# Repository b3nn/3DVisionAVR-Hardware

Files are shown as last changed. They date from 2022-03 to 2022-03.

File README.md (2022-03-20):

# 3DVisionAVR-Hardware
Hardware design files and info for 3DVisionAVR, a clone for 3D Vision Emitter using IR. This is a hardware implementation to use with Lukis101's [3DVisionAVR](https://github.com/lukis101/3DVisionAVR) code

# Notice
This is at an early stage and may change significantly. It should not be considered a replacement for the official 3D Vision Emitter pyramid. You will likely notice limited range of the IR signal and sync issues. Consider this a work in progress which you can help test and improve

# Design Files
This was designed in Kicad v6 and uses [g200kg's kicad-lib-arduino](https://github.com/g200kg/kicad-lib-arduino) library for the Sparkfun Pro Micro

The main component is an Arduino Pro Micro. This should work fine with a clone version to save a few dollars. However, to make things easy, all items can be purchased via the [Sparkfun Wishlist 167547](https://www.sparkfun.com/wish_lists/167547) for around $50 USD. 

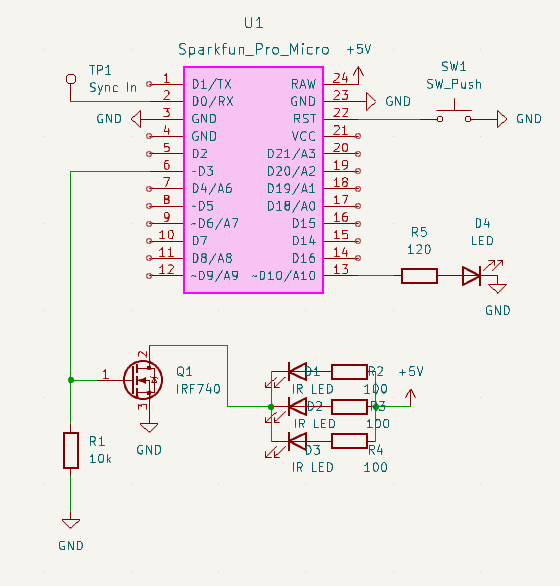
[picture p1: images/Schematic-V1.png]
schematic


# Breadboarding
The circuit is easy to create on a breadboard.

- Pro Micro PIN 3 is our IR Signal (goes to mosfet Gate)
- Pro Micro PIN 10 is USB Status light (goes to resistor to green led)
- Pro Micro RAW is IR LED Power (goes to positive rail)

Hook up GND on both sides of the Pro Micro to the negative rail. The mosfet source pin goes to GND and the middle drain pin goes to the cathode pin of the IR leds (short leg). Wire Pin 3 from the Pro Micro to the gate on the mosfet and then a pull down 10K resistor (connected to the negative rail). Each IR Led should have the anode (long leg) connected via a 100 ohm resistor to the RAW positive rail. Finally hook up the status LED to the signal on Pin 10 (it might be unlabeled but next to pin 16). 

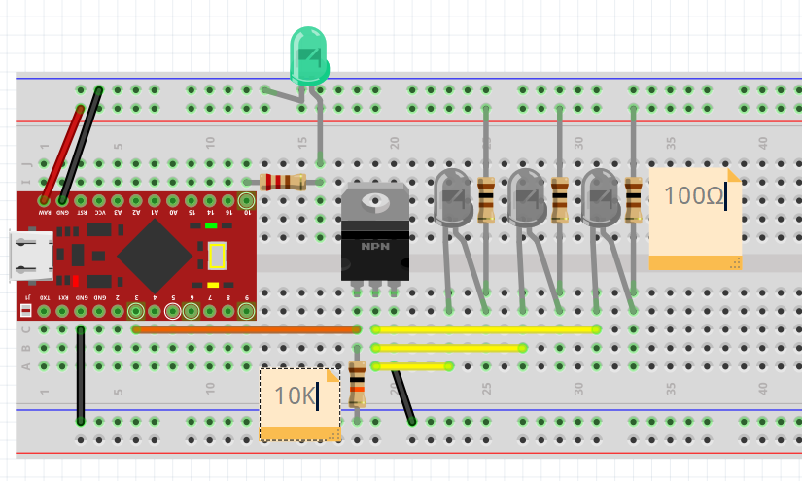
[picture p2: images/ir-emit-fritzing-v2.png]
Fritzing Breadboard


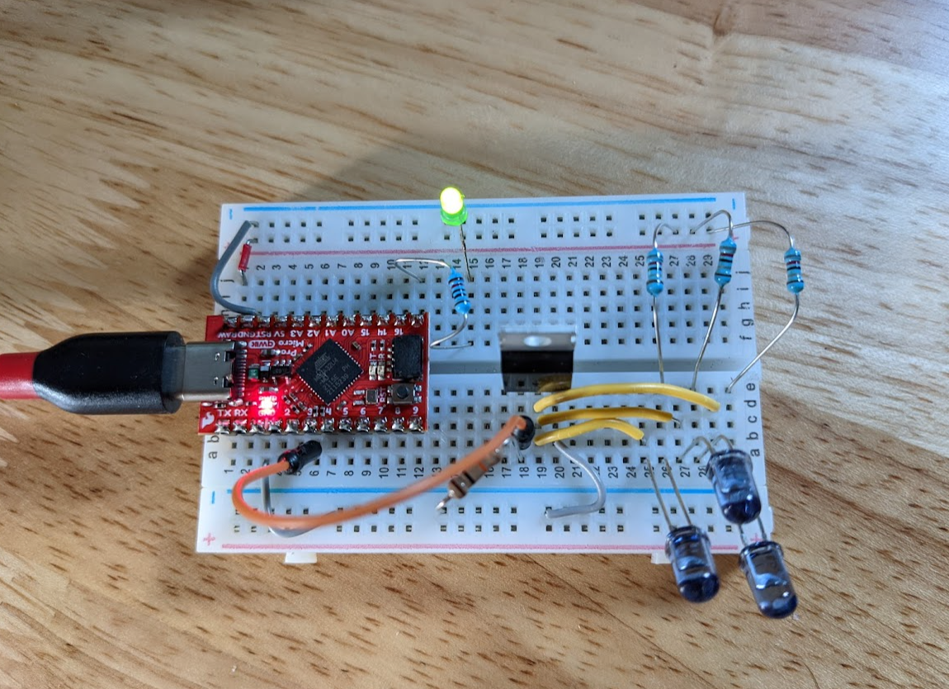
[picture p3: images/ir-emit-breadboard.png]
IRL Breadboard


Also if you are using the VESA sync, that goes into the Pro Micro PIN 2. Point the IR LEDs at your face for best results :-)

# PCB
I'm currently having this PCB fabricated, but all files are here if you would also like to fab your own. This is using common through-hole parts so it can be packaged into an easy to assemble kit.

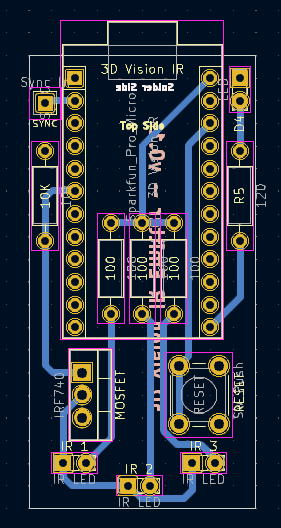
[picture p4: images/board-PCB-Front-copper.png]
PCB Front Copper


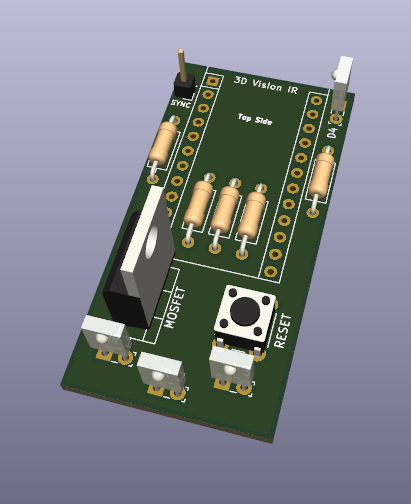
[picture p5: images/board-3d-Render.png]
board-3d-Render


# Flashing
For steps on compiling and flashing Lukis101's [3DVisionAVR](https://github.com/lukis101/3DVisionAVR) code for this project, view [README-FLASH-FIRMWARE.md](README-FLASH-FIRMWARE.md)

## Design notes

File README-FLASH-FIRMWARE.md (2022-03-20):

# 3DVisionAVR Firmware
Flashing the Arduino Pro Micro with the [3DVisionAVR](https://github.com/lukis101/3DVisionAVR) code does require a few tools and steps. In order to help others with that process, here is what worked for me on Windows 10.

Download and install [Arduino IDE](https://www.arduino.cc/en/software) and [Microchip Studio](https://www.microchip.com/en-us/tools-resources/develop/microchip-studio#Downloads) for AVR (at the time, my versions were Arduino 1.8.10 and Studio v7.0.2542). 

Download lukis101's code from Github and make sure to include the lufa submodule. I recommend using git command for this:

    git clone --recurse-submodules https://github.com/lukis101/3DVisionAVR.git

Next open the [3DvisionAVR.atsln](https://github.com/lukis101/3DVisionAVR/blob/master/3DVisionAVR.atsln) file in Microchip Studio. I made one change since I'm doing the software only driver. Open the [IREmitter.c](https://github.com/lukis101/3DVisionAVR/blob/master/3DVisionAVR/IREmitter.c#L40) file and change 

**IR_SetSyncMode(SYNCMODE_COMBINED);**

over to the software only driver mode

**IR_SetSyncMode(SYNCMODE_DRIVER);**

Save the file, then go under the BUILD menu to BUILD SOLUTION. Read the output window and make sure you got a "Build succeeded" message. At this point, you have the compiled code, but we need to flash that to the Pro Micro.

# Flashing

You will need to manually set the COM port of the Pro Micro to flash it. Here's one way to get that. Plug in the Pro Micro. Open the Window's DEVICE MANAGER _(devmgmt.msc)_ and expand the PORTS section. You should see a COM port for the Pro Micro, however, we need the bootloader COM port. This is typically one number higher than the default one you'll see. So if it says "COM8", you can assume the bootloader we want is at "COM9". To test this, quickly double tap the RESET button on the Pro Micro (if your Pro Micro does not have a reset button, you [achieve the same thing](https://learn.sparkfun.com/tutorials/pro-micro--fio-v3-hookup-guide/troubleshooting-and-faq) by shorting the RESET Pin to GND twice quickly). This will enter the bootloader mode for 7 seconds and the correct com port will quickly be listed in device manager. If you double tap at the wrong speed, the device just resets instead of entering the bootloader mode, so it may take a few tries.

We are flashing the code via Microchip Studio, but it uses the Arduino tools for the process. If you've installed Arduino IDE into a different directory, you will need to change these file paths to match yours. In Microchip Studio go under TOOLS to the EXTERNAL TOOLS option. Add a new entry:

    Title: Arduino Pro Micro
    
    Command: C:\Program Files (x86)\Arduino\hardware\tools\avr\bin\avrdude.exe
    
    Arguments: -C"C:\Program Files (x86)\arduino\hardware\tools\avr\etc\avrdude.conf" -v -patmega32u4 -cavr109 -PCOM9 -b57600 -D -Uflash:w:"$(ProjectDir)\3DVisionAVR.hex":i

Check the "Use Output window" option then Apply the changes. You will need to change the **-PCOM9** in the Arguments to match your bootloader com port as mentioned above.

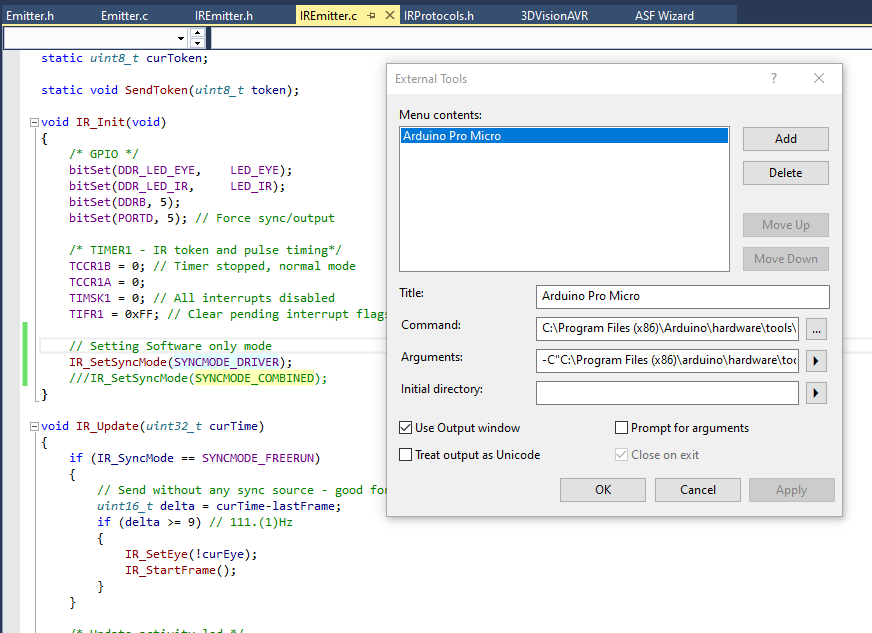
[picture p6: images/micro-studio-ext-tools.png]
MicroStudio External Tool Setup


Make sure you have a compiled build (BUILD menu to BUILD SOLUTION) and your Pro Micro is plugged in over USB. You will need to quickly double tap the RESET button on the Pro Micro, then in Microchip Studio select under the TOOLS menu the new "Arduino Pro Micro" command. If you do this at the wrong speed, you'll either get an error message about the com port not being found or sometimes sync errors. This is tricky and took me about 5 tries until I got it the first time. Always read the output window.

If everything worked correctly, Device Manager will now have under "Universal Serial Bus controllers" a new "NVIDIA Stereoscopic 3d USB controller" and 3D Manager will show an IR emitter as Connected.

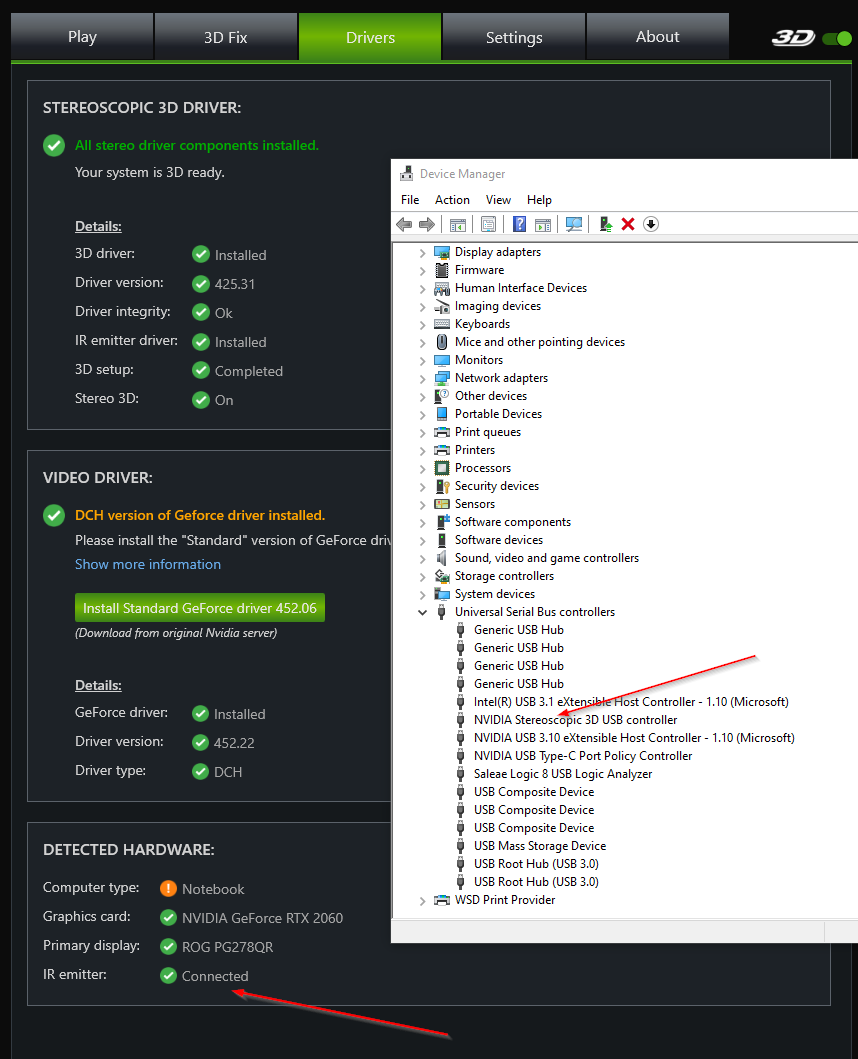
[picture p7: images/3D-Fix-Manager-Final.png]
3D Fix Manager


Now launch your game via 3D Fix Manager like normal.

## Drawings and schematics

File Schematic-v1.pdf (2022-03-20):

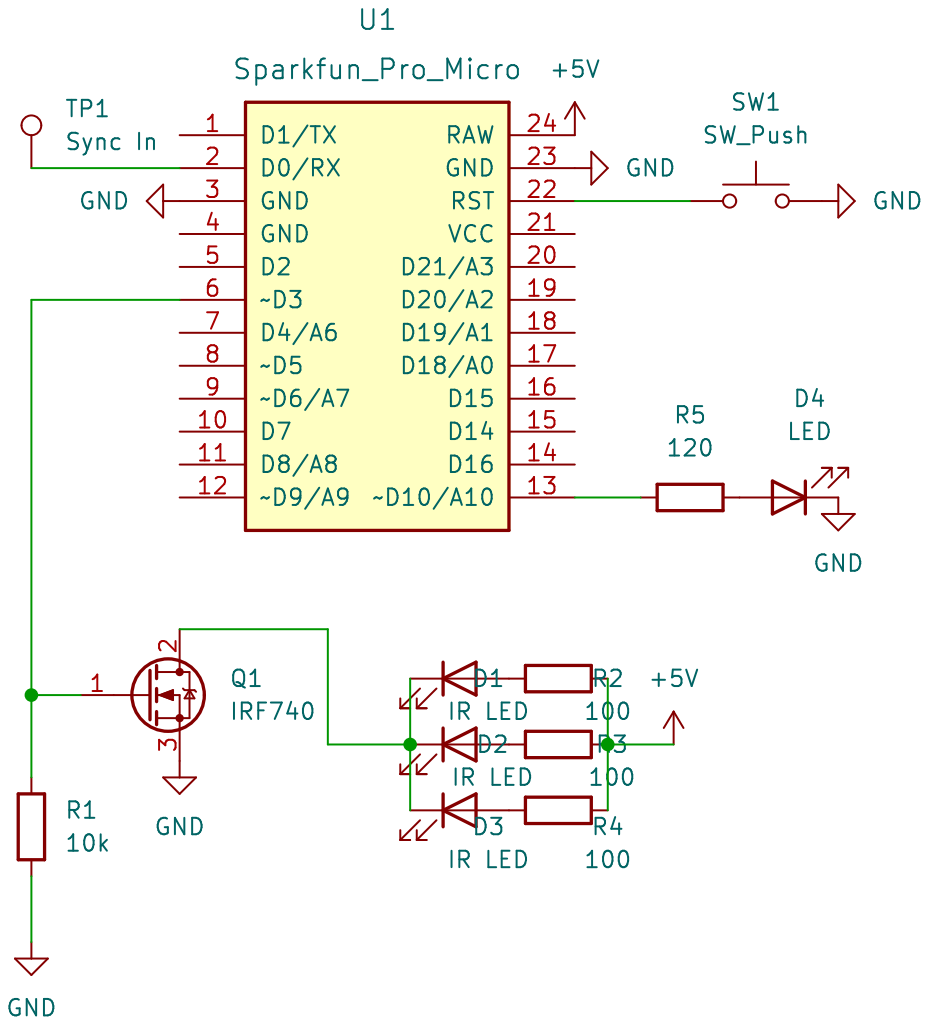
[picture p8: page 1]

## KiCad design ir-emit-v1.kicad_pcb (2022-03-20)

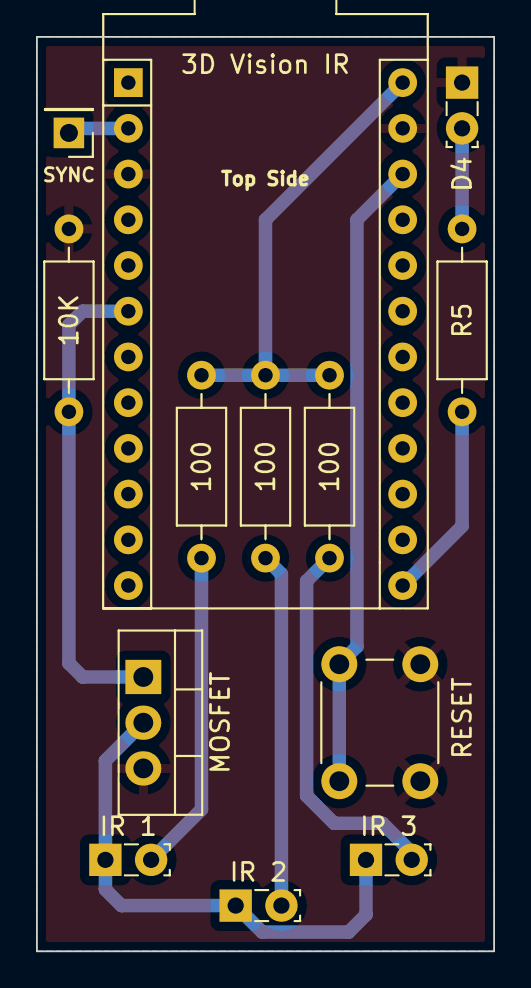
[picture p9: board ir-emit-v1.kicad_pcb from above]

Board: 2 copper layers, 25.4 x 50.8 mm, 13 parts (0 on the bottom side), 11 nets.

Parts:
3D Vision IR: Sparkfun_Pro_Micro
10K: 10k; R_Axial_DIN0207_L6.3mm_D2.5mm_P10.16mm_Horizontal
100, 100#2, 100#3: 100; R_Axial_DIN0207_L6.3mm_D2.5mm_P10.16mm_Horizontal
D4: LED; LED_SideEmitter_Rectangular_W4.5mm_H1.6mm
IR 1, IR 2, IR 3: IR LED; LED_SideEmitter_Rectangular_W4.5mm_H1.6mm
MOSFET: IRF740; TO-220-3_Vertical
R5: 120; R_Axial_DIN0207_L6.3mm_D2.5mm_P10.16mm_Horizontal
RESET: SW_Push; SW_PUSH_6mm
SYNC: Sync In; PinHeader_1x01_P2.54mm_Vertical

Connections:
+5V: 3D Vision IR.24 (RAW), 100.2, 100#2.2, 100#3.2
GND: 3D Vision IR.3 (GND), 3D Vision IR.23 (GND), 10K.2, D4.1 (K), MOSFET.3 (S), RESET.2
unnamed: IR 1.1 (K), IR 2.1 (K), IR 3.1 (K), MOSFET.2 (D)
unnamed: 100#2.1, IR 1.2 (A)
unnamed: 100.1, IR 2.2 (A)
unnamed: 100#3.1, IR 3.2 (A)
unnamed: D4.2 (A), R5.2
unnamed: 3D Vision IR.6 (~D3), 10K.1, MOSFET.1 (G)
unnamed: 3D Vision IR.13 (~D10/A10), R5.1
unnamed: 3D Vision IR.22 (RST), RESET.1
unnamed: 3D Vision IR.2 (D0/RX), SYNC.1

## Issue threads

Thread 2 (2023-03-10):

Compiler error

KoalaRX, 2023-03-10:
Hi b3nn,
using the same avr studio version i'm getting the following error while Building. I've Checked the Makefile for mismatched Path's but all seem to be ok. Can you confirm that the current Codebase is still ok on Github? Is there any ability of setting the compiler to verbose mode, so it puts out more Status messages to determinate when in the process the compiler is missing something (like in the output below "the system cannot find the specified path.")
Thanks for helping, I would be really happy getting this project build and try building the breadboard circut you described.

------ Build started: Project: 3DVisionAVR, Configuration: Debug AVR ------
Build started.
Project "3DVisionAVR.cproj" (default targets):
Target "PreBuildEvent" skipped, due to false condition; ('$(PreBuildEvent)'!='') was evaluated as (''!='').
Target "CoreBuild" in file "C:\Program Files (x86)\Atmel\Studio\7.0\Vs\Compiler.targets" from project "C:\Users\usr\Documents\test\3DVisionAVR\3DVisionAVR.cproj" (target "Build" depends on it):
	Task "RunCompilerTask"
		Shell Utils Path C:\Program Files (x86)\Atmel\Studio\7.0\shellUtils
		C:\Program Files (x86)\Atmel\Studio\7.0\shellUtils\make.exe -C "C:\Users\usr\Documents\test\3DVisionAVR" -f "makefile" all
		make: Entering directory 'C:/Users/usr/Documents/test/3DVisionAVR'
		the system cannot find the specified path.
		the system cannot find the specified path.
		the system cannot find the specified path.
		' [INFO]    :' Begin compilation of project \"3DVisionAVR\"...
		""
		avr-gcc (AVR_8_bit_GNU_Toolchain_3.6.2_1778) 5.4.0
		Copyright (C) 2015 Free Software Foundation, Inc.
		This is free software; see the source for copying conditions.  There is NO
		warranty; not even for MERCHANTABILITY or FITNESS FOR A PARTICULAR PURPOSE.
		' [GCC]     :' Compiling C file \"Emitter.c\"
		avr-gcc -c -pipe -gdwarf-2 -g2 -mmcu=atmega32u4 -fshort-enums -fno-inline-small-functions -Wall -fno-strict-aliasing -funsigned-char -funsigned-bitfields -ffunction-sections -I. -DARCH=ARCH_AVR8 -DDMBS_ARCH_AVR8 -mrelax -fno-jump-tables -x c -O2 -std=gnu99 -Wstrict-prototypes -DF_CPU=16000000UL -DUSE_LUFA_CONFIG_HEADER -IConfig/ -I. -I../lufa/LUFA/.. -DARCH=ARCH_AVR8 -DBOARD=BOARD_NONE -DF_USB=16000000UL   -MMD -MP -MF obj/Emitter.d Emitter.c -o obj/Emitter.o
		Assembler messages:
RUNCOMPILERTASK(0,0): error: can't create obj/Emitter.o: No such file or directory
C:\Users\usr\Documents\test\3DVisionAVR\Emitter.c(314,1): error: error writing to -: Invalid argument
		 }
		 ^
		compilation terminated.
		make: *** [obj/Emitter.o] Error 1
C:\Users\usr\Documents\test\lufa\LUFA\Build\DMBS\DMBS\gcc.mk(225,1): error: recipe for target 'obj/Emitter.o' failed
		make: Leaving directory 'C:/Users/usr/Documents/test/3DVisionAVR'
		The command exited with code 2.
	Done executing task "RunCompilerTask" -- FAILED.
Done building target "CoreBuild" in project "3DVisionAVR.cproj" -- FAILED.
Done building project "3DVisionAVR.cproj" -- FAILED.

Build FAILED.
========== Build: 0 succeeded or up-to-date, 1 failed, 0 skipped ==========

b3nn, 2023-03-11:
Hi KoalaRX,
Yes, it's still building for me and it does look like we're using the same version of AVR Studio. The _"the system cannot find the specified path_" error message makes me think there could be a permissions issue with accessing your user's Documents directory.  Have you tried moving the source code to something outside of your Documents directory and then building from there? I'm building from "D:\Code" and haven't seen this issue, but this is the only project I'm using AVR Studio with.
